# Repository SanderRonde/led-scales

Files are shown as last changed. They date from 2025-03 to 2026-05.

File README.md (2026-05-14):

# LED Scales

A Python-based tool for generating LED scale patterns.

## Preview

Physical build with the web controller driving the LEDs:

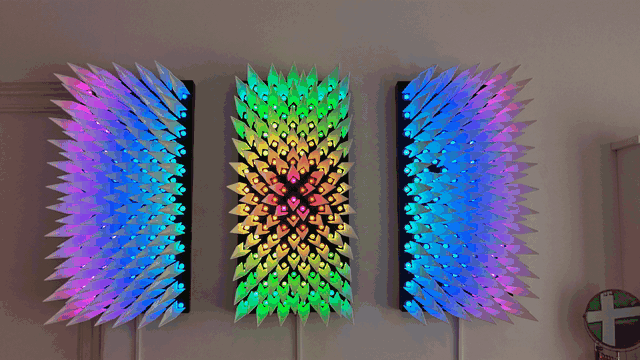
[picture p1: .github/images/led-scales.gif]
LED scales in motion


CAD layout examples (tile patterns generated by this project):

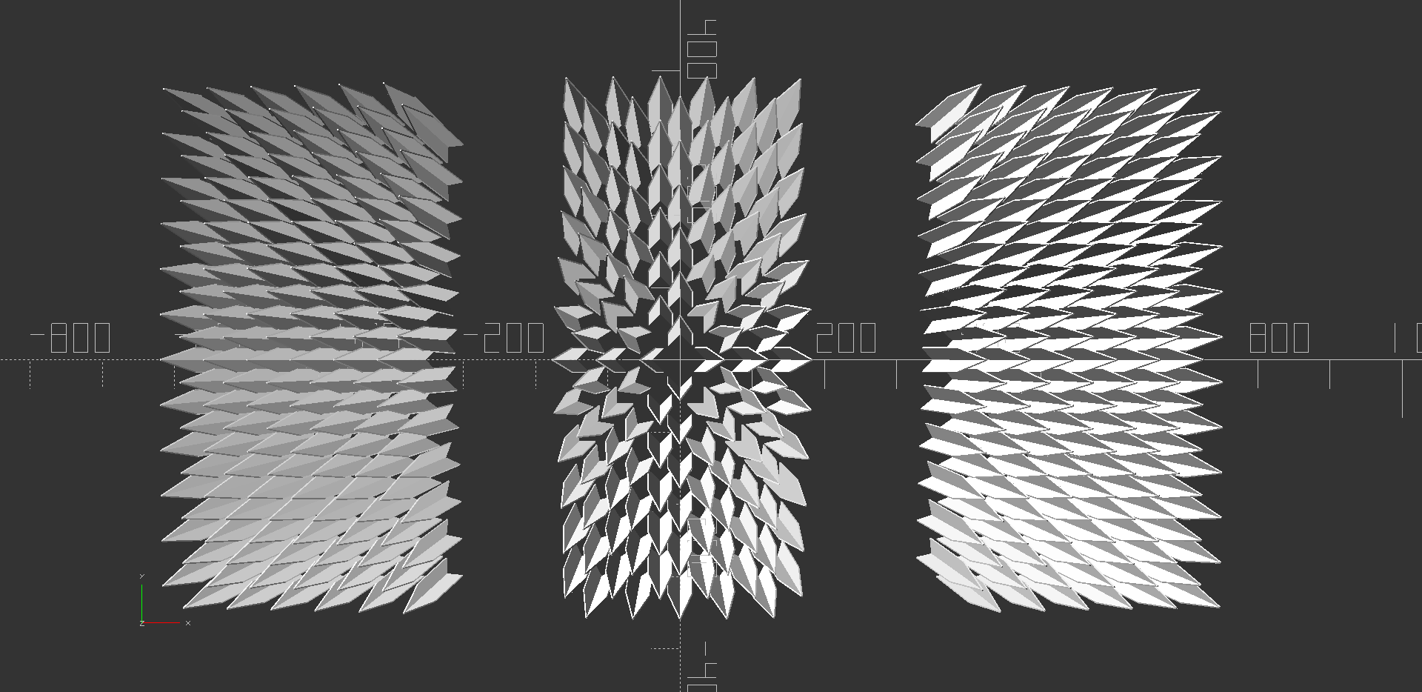
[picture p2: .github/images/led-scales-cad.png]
CAD scale patterns


A higher-quality copy of the clip lives in [`.github/images/led-scales.mp4`](.github/images/led-scales.mp4).

## Project Structure

The project is split into two main components, each with its own virtual environment:
1. CAD Generation (`venv-cad`) - For creating 3D printable scales and panel layouts
2. LED Control (`venv-led`) - For controlling the LED patterns through a web interface

## Virtual Environments

The project uses separate virtual environments for each component to keep dependencies clean and isolated:

- `venv-cad` - Contains dependencies for CAD generation (numpy, openpyscad, scipy)
- `venv-led` - Contains dependencies for LED control (Flask, WebSocket, etc.)

Virtual environments are created and managed automatically when you run the respective commands.

## How to generate files

1. Open `config.py` and set the parameters to your liking. Be sure to update `scad_path` to the path of your OpenSCAD installation.
2. Set up both virtual environments: `python main.py setup`
3. Run `python main.py all` to generate all the necessary files
   - This will automatically use the CAD virtual environment

## Development

- For LED development: `python main.py dev` 
  - Starts a development server with auto-reload
  - Uses the LED virtual environment
- For CAD development: `python main.py generate` (or `2d`/`3d`)
  - Uses the CAD virtual environment
- For linting: `python main.py lint`
  - Uses the CAD virtual environment (contains pylint)

## How to use

1. Inspect the `cad/out` directory to see if the results are satisfactory. Adjust `config.py` if necessary. Also use `python main.py leds-mock` to see what the LEDs will look like.
2. 3D print the tiles in `cad/out/tiles/`. Each tile can be printed on a single build plate. Keep them separated!
3. Order panels (material is up to you, I went with alupanel) with dimensions as outputted by the `all` command above. I'd recommend 3+mm thick.
4. Print out the template in `cad/out/panels/` onto paper.
5. Choose and order LEDs. I went with WS2812B strings (specifically [these](https://aliexpress.com/item/33044727740.html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))
6. Drill holes for the LEDs on the panels (see template for location). Hole size should of course be the same as the LED. Mark the orientation of scales on the panels (I used a knife through the paper).
7. Print diffusers for the LEDs.
8. Wire LEDs through the back of the holes, put a diffuser on the front of the holes, use hot glue to stick them in place.
9. Assemble the scales on the marked locations. By starting out from the middle and simply going through print order you'll increase the curve as you go. Alternatively use `out/led-scales-py.positioning.scad` to get exact locations.
10. Wire LEDs to the power supply.
11. Get a raspberry pi and run the server (`python main.py leds`). Visit the web page to both see a preview and to control the effects.
12. Turn on the power and enjoy!

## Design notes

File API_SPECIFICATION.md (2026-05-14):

# LED Control System - API Specification v1.0

## Overview

This is a comprehensive API specification for the LED Control System. The system provides both HTTP REST endpoints and Socket.IO real-time communication for controlling LED effects, managing power state, brightness, and presets.

**Base URL**: `http://localhost:5001` (configurable via `web_port` in config)

**Transport Protocols**:

-   HTTP/REST for state changes and configuration
-   Socket.IO for real-time LED updates and bidirectional communication

---

## Table of Contents

1. [HTTP REST API](#http-rest-api)
    - [Effects Management](#effects-management)
    - [State Management](#state-management)
    - [Presets Management](#presets-management)
    - [Configuration](#configuration)
    - [Static Assets](#static-assets)
2. [Socket.IO API](#socketio-api)
    - [Events from Server](#events-from-server)
    - [Connection Handling](#connection-handling)
3. [Data Models](#data-models)
4. [Authentication](#authentication)
5. [Error Handling](#error-handling)
6. [Examples](#examples)

---

## HTTP REST API

### Effects Management

#### GET /effects

Get all available effects with their parameters and current effect.

**Request:**

```http
GET /effects HTTP/1.1
Host: localhost:5001
```

**Response:** `200 OK`

```json
{
    "effect_parameters": {
        "RainbowRadialEffect": {
            "speed": {
                "type": "float",
                "description": "Speed of the rainbow animation",
                "value": 0.5
            },
            "intensity": {
                "type": "float",
                "description": "Intensity of the colors",
                "value": 1.0
            }
        },
        "SingleColorEffect": {
            "color": {
                "type": "color",
                "description": "The color to display",
                "value": {
                    "r": 255,
                    "g": 0,
                    "b": 0
                }
            }
        },
        "RandomColorHexEffect": {
            "transition_speed": {
                "type": "float",
                "description": "Speed of color transitions",
                "value": 0.3
            }
        }
    },
    "effect_names": {
        "RainbowRadialEffect": "Rainbow Radial",
        "SingleColorEffect": "Single Color",
        "RandomColorHexEffect": "Random Color Hex",
        "RainbowSpinEffect": "Rainbow Spin",
        "MultiColorRadialEffect": "Multi Color Radial"
    },
    "current_effect": "RainbowRadialEffect"
}
```

**Response Fields:**

-   `effect_parameters` (object): Map of effect class names to their parameter definitions
-   `effect_names` (object): Map of effect class names to human-readable names
-   `current_effect` (string): The currently active effect class name

---

#### POST /effects

Set the current effect and optionally update its parameters.

**Request:**

```http
POST /effects HTTP/1.1
Host: localhost:5001
Content-Type: application/json

{
  "effect_name": "SingleColorEffect",
  "parameters": {
    "color": {
      "r": 255,
      "g": 128,
      "b": 0
    }
  }
}
```

**Request Body:**

-   `effect_name` (string, required): The class name of the effect to activate
-   `parameters` (object, optional): Key-value pairs of parameter names and values

**Response:** `200 OK`

```json
{
    "success": true
}
```

**Error Responses:**

`400 Bad Request` - Missing effect name

```json
{
    "success": false,
    "error": "No effect name provided"
}
```

`404 Not Found` - Effect not found

```json
{
    "success": false,
    "error": "Effect \"InvalidEffect\" not found"
}
```

**Side Effects:**

-   Saves configuration to disk (`~/.led_config.json`)
-   Clears `active_preset_id` since effect/parameters were modified
-   Starts the effect if not already running
-   Emits `effects_update` and `state_update` Socket.IO events to all connected clients

---

### State Management

#### GET /state

Get the current power state, target power state, and brightness.

**Request:**

```http
GET /state HTTP/1.1
Host: localhost:5001
```

**Response:** `200 OK`

```json
{
    "power_state": true,
    "target_power_state": true,
    "brightness": 0.85,
    "active_preset_id": 1697123456789,
    "default_preset_id": 1697123456790,
    "power_on_at_startup": true
}
```

**Response Fields:**

-   `power_state` (boolean): Current power state (may be transitioning)
-   `target_power_state` (boolean): Target power state after fade completes
-   `brightness` (float): Brightness level (0.0 to 1.0)
-   `active_preset_id` (number|null): ID of the currently active preset, or null if no preset is active
-   `default_preset_id` (number|null): ID of the preset applied automatically on server startup, or null if none
-   `power_on_at_startup` (boolean): Whether the server begins with strips powered on after a restart. If the key is absent from disk config, this matches legacy behavior using the last saved `power_state`. Change it with `POST /state` (optional body field).

---

#### POST /state

Update the power state, brightness, and/or startup power preference.

**Request:**

```http
POST /state HTTP/1.1
Host: localhost:5001
Content-Type: application/json

{
  "power_state": false,
  "brightness": 0.5
}
```

**Request (startup preference only):**

```http
POST /state HTTP/1.1
Host: localhost:5001
Content-Type: application/json

{
  "power_on_at_startup": false
}
```

**Request Body:**

-   `power_state` (boolean, optional): Set the target power state
-   `brightness` (float, optional): Set the brightness (0.0 to 1.0)
-   `power_on_at_startup` (boolean, optional): Persist whether strips should start **on** after the next server restart (`false` = start off). Does not change current power unless `power_state` is also sent.

**Response:** `200 OK`

```json
{
    "success": true,
    "power_state": true,
    "target_power_state": false,
    "brightness": 0.5,
    "active_preset_id": null,
    "default_preset_id": 1697123456790,
    "power_on_at_startup": true
}
```

**Notes:**

-   Power state changes trigger a 300ms fade transition
-   During the fade, `power_state` and `target_power_state` will differ
-   Brightness is clamped to range [0.0, 1.0]
-   If `power_on_at_startup` is present but not a JSON boolean, the server returns `400 Bad Request`

**Error Responses:**

`400 Bad Request` — `power_on_at_startup` is not a boolean

```json
{
    "error": "\"power_on_at_startup\" must be a boolean"
}
```

**Side Effects:**

-   Saves configuration to disk
-   Persists `power_on_at_startup` when that field is included in the request body
-   Starts fade transition for power changes
-   Clears `active_preset_id` when brightness is modified
-   Emits `state_update` Socket.IO event to all connected clients

---

### Presets Management

#### GET /presets

Get all saved presets.

**Request:**

```http
GET /presets HTTP/1.1
Host: localhost:5001
```

**Response:** `200 OK`

```json
[
    {
        "id": 1697123456789,
        "name": "Cozy Orange",
        "effect": "SingleColorEffect",
        "brightness": 0.6,
        "parameters": {
            "color": {
                "r": 255,
                "g": 128,
                "b": 0
            }
        }
    },
    {
        "id": 1697123456790,
        "name": "Rainbow Party",
        "effect": "RainbowRadialEffect",
        "brightness": 1.0,
        "parameters": {
            "speed": 0.8
        }
    }
]
```

**Response:** Array of preset objects with:

-   `id` (number): Unique identifier (Unix timestamp in milliseconds)
-   `name` (string): User-defined preset name
-   `effect` (string): Effect class name
-   `brightness` (float): Brightness level (0.0 to 1.0)
-   `parameters` (object): Effect parameters

---

#### POST /presets

Create a new preset or update an existing one.

**Request (Create New):**

```http
POST /presets HTTP/1.1
Host: localhost:5001
Content-Type: application/json

{
  "name": "Cool Blue",
  "effect": "SingleColorEffect",
  "brightness": 0.7,
  "parameters": {
    "color": {
      "r": 0,
      "g": 100,
      "b": 255
    }
  }
}
```

**Request (Update Existing):**

```http
POST /presets HTTP/1.1
Host: localhost:5001
Content-Type: application/json

{
  "id": 1697123456789,
  "name": "Updated Name",
  "effect": "SingleColorEffect",
  "brightness": 0.8,
  "parameters": {
    "color": {
      "r": 200,
      "g": 100,
      "b": 50
    }
  }
}
```

**Request Body:**

-   `id` (number, optional): If provided, updates existing preset with this ID
-   `name` (string, required): Preset name
-   `effect` (string, required): Effect class name
-   `brightness` (float, required): Brightness level (0.0 to 1.0)
-   `parameters` (object, required): Effect parameters

**Response:** `200 OK`

```json
{
    "id": 1697123456791,
    "name": "Cool Blue",
    "effect": "SingleColorEffect",
    "brightness": 0.7,
    "parameters": {
        "color": {
            "r": 0,
            "g": 100,
            "b": 255
        }
    }
}
```

**Error Response:** `400 Bad Request`

```json
{
    "error": "Invalid preset data"
}
```

**Side Effects:**

-   Saves configuration to disk
-   Emits `presets_update` Socket.IO event to all connected clients

---

#### DELETE /presets/{preset_id}

Delete a preset by ID.

**Request:**

```http
DELETE /presets/1697123456789 HTTP/1.1
Host: localhost:5001
```

**Response:** `200 OK`

```json
{
    "success": true
}
```

**Side Effects:**

-   Saves configuration to disk
-   Emits `presets_update` Socket.IO event to all connected clients
-   If the deleted preset was the startup default, clears `default_preset_id` and emits `state_update`

---

#### POST /presets/default

Set or clear which preset is applied automatically when the LED server starts. This does not change the current effect until the next restart (unless you also call `POST /presets/apply`).

**Request:**

```http
POST /presets/default HTTP/1.1
Host: localhost:5001
Content-Type: application/json

{
  "id": 1697123456789
}
```

**Request Body:**

-   `id` (number|null, required): Preset ID to use on startup, or `null` to clear the default

**Response:** `200 OK`

```json
{
    "success": true,
    "default_preset_id": 1697123456789
}
```

When clearing the default:

```json
{
    "success": true,
    "default_preset_id": null
}
```

**Error Responses:**

`400 Bad Request` — Missing `id` key

```json
{
    "error": "JSON body must include \"id\" (preset id or null to clear)"
}
```

`404 Not Found` — Preset id is not in the saved presets list

```json
{
    "error": "Preset not found"
}
```

**Side Effects:**

-   Saves `default_preset_id` to `~/.led_config.json`
-   Emits `state_update` Socket.IO event to all connected clients

---

#### POST /presets/apply

Apply a preset to the LED system.

**Request:**

```http
POST /presets/apply HTTP/1.1
Host: localhost:5001
Content-Type: application/json

{
  "id": 1697123456789,
  "effect": "SingleColorEffect",
  "brightness": 0.7,
  "parameters": {
    "color": {
      "r": 0,
      "g": 100,
      "b": 255
    }
  }
}
```

**Request Body:**

-   `id` (number, optional): Preset ID to set as active
-   `effect` (string, required): Effect class name
-   `brightness` (float, optional): Brightness level (0.0 to 1.0)
-   `parameters` (object, optional): Effect parameters

**Response:** `200 OK`

```json
{
    "success": true
}
```

**Error Response:** `400 Bad Request`

```json
{
    "error": "No preset data provided"
}
```

**Side Effects:**

-   Changes current effect
-   Updates effect parameters
-   Sets brightness
-   Sets `active_preset_id` to the preset's ID
-   Saves configuration to disk
-   Starts effect if not running
-   Emits `effects_update` and `state_update` Socket.IO events

---

### Configuration

#### GET /config

Get the visualizer configuration (LED layout and controller type).

**Request:**

```http
GET /config HTTP/1.1
Host: localhost:5001
```

**Response (Hexagon Layout):** `200 OK`

```json
{
  "type": "hex",
  "led_count": 488,
  "hexagons": [
    {
      "x": 0,
      "y": 1,
      "ordered_leds": [216, 217, 218, 219, 220, 248, 249, 250, 251, 252, ...]
    },
    {
      "x": 0,
      "y": 2,
      "ordered_leds": [189, 190, 191, 192, 193, 303, 304, 305, 306, ...]
    }
  ]
}
```

**Response (Scale Panel Layout):** `200 OK`

```json
{
    "type": "scale",
    "led_count": 648,
    "panels": [
        {
            "panel_index": 0,
            "x_offset": 0,
            "y_offset": 0,
            "led_positions": [
                { "index": 0, "x": 27.5, "y": 27.5 },
                { "index": 1, "x": 82.5, "y": 27.5 }
            ]
        }
    ],
    "spacing": 55,
    "panel_width": 330,
    "panel_height": 632.5
}
```

**Response Fields:**

Common:

-   `type` (string): Layout type - `"hex"` or `"scale"`
-   `led_count` (number): Total number of LEDs

Hex Layout:

-   `hexagons` (array): Array of hexagon objects
    -   `x` (number): Hexagon X position
    -   `y` (number): Hexagon Y position (may be half-integer for offset rows)
    -   `ordered_leds` (array): LED indices in this hexagon, in spiral order

Scale Layout:

-   `panels` (array): Array of panel objects
    -   `panel_index` (number): Panel index
    -   `x_offset` (number): Panel X offset in mm
    -   `y_offset` (number): Panel Y offset in mm
    -   `led_positions` (array): LED positions within panel
        -   `index` (number): Global LED index
        -   `x` (number): X position in mm
        -   `y` (number): Y position in mm
-   `spacing` (number): Spacing between LEDs in mm
-   `panel_width` (number): Panel width in mm
-   `panel_height` (number): Panel height in mm

---

### Static Assets

#### GET /

Serves the main visualizer web interface.

**Request:**

```http
GET / HTTP/1.1
Host: localhost:5001
```

**Response:** `200 OK`

```html
<!DOCTYPE html>
<html>
    <head>
        <title>LED Visualizer</title>
        ...
    </head>
    <body>
        ...
    </body>
</html>
```

---

#### GET /static/{filename}

Serves static files (JavaScript, CSS, images).

**Request:**

```http
GET /static/js/index.js HTTP/1.1
Host: localhost:5001
```

**Response:** `200 OK`

```javascript
// JavaScript content
```

**Supported File Types:**

-   `.js` - JavaScript files (MIME: `application/javascript`)
-   `.css` - CSS files (MIME: `text/css`)
-   `.html` - HTML files (MIME: `text/html`)
-   `.json` - JSON files (MIME: `application/json`)
-   `.svg` - SVG images (MIME: `image/svg+xml`)

---

## Socket.IO API

### Connection

**Endpoint:** `ws://localhost:5001/socket.io/`

**Namespace:** `/` (default namespace)

**CORS:** Allowed from all origins (`*`)

**Protocol:** Socket.IO v4 compatible

### Connection Handling

#### Event: `connect`

Emitted by client when connecting to the server.

**Server Response:**

Upon connection, the server automatically emits three events:

1. `state_update` - Current power and brightness state
2. `effects_update` - Available effects and current effect
3. `presets_update` - All saved presets

**Example Client Code:**

```javascript
import io from "socket.io-client";

const socket = io("http://localhost:5001");

socket.on("connect", () => {
    console.log("Connected to LED server");
});
```

---

### Events from Server

#### Event: `led_update`

Real-time LED color data. Emitted continuously (approx 20-200 times per second depending on configuration).

**Payload:**

```json
{
  "leds": [
    {"r": 255, "g": 0, "b": 0, "w": 0},
    {"r": 255, "g": 32, "b": 0, "w": 0},
    {"r": 255, "g": 64, "b": 0, "w": 0},
    ...
  ]
}
```

**Payload Fields:**

-   `leds` (array): Array of LED color objects in index order
    -   `r` (number): Red component (0-255)
    -   `g` (number): Green component (0-255)
    -   `b` (number): Blue component (0-255)
    -   `w` (number): White component (0-255)

**Client Handler Example:**

```javascript
socket.on("led_update", (data) => {
    // Update visualizer with new LED colors
    data.leds.forEach((color, index) => {
        updateLED(index, color);
    });
});
```

---

#### Event: `state_update`

Emitted when power state, brightness, startup default preset, or startup power preference changes.

**Payload:**

```json
{
    "power_state": true,
    "target_power_state": false,
    "brightness": 0.75,
    "active_preset_id": 1697123456789,
    "default_preset_id": 1697123456790,
    "power_on_at_startup": true
}
```

**Payload Fields:**

-   `power_state` (boolean): Current power state
-   `target_power_state` (boolean): Target power state (differs during fade)
-   `brightness` (float): Brightness level (0.0 to 1.0)
-   `active_preset_id` (number|null): ID of the currently active preset, or null if no preset is active
-   `default_preset_id` (number|null): ID of the preset applied on server startup, or null if none
-   `power_on_at_startup` (boolean): Whether the server will start with power on after the next restart

**Triggered By:**

-   Client connects
-   `POST /state` (power, brightness, and/or `power_on_at_startup`)
-   Preset applied
-   `POST /presets/default`
-   `DELETE /presets/{id}` when the removed preset was the startup default

**Client Handler Example:**

```javascript
socket.on("state_update", (data) => {
    console.log(
        `Power: ${data.power_state}, Brightness: ${data.brightness * 100}%`
    );
    console.log(`Active preset: ${data.active_preset_id || "None"}`);
    console.log(`Startup default: ${data.default_preset_id || "None"}`);
    console.log(`Power on at next startup: ${data.power_on_at_startup}`);
    updatePowerButton(data.power_state);
    updateBrightnessSlider(data.brightness);
    highlightActivePreset(data.active_preset_id);
});
```

---

#### Event: `effects_update`

Emitted when the current effect or available effects change.

**Payload:**

```json
{
    "effect_parameters": {
        "RainbowRadialEffect": {
            "speed": {
                "type": "float",
                "description": "Animation speed",
                "value": 0.5
            }
        },
        "SingleColorEffect": {
            "color": {
                "type": "color",
                "description": "Display color",
                "value": { "r": 255, "g": 0, "b": 0 }
            }
        }
    },
    "effect_names": {
        "RainbowRadialEffect": "Rainbow Radial",
        "SingleColorEffect": "Single Color"
    },
    "current_effect": "RainbowRadialEffect"
}
```

**Payload Fields:**

-   `effect_parameters` (object): Map of effect class names to parameter definitions
-   `effect_names` (object): Map of effect class names to display names
-   `current_effect` (string): Currently active effect class name

**Triggered By:**

-   Client connects
-   POST /effects endpoint called
-   Effect changed via preset

**Client Handler Example:**

```javascript
socket.on("effects_update", (data) => {
    console.log(`Current effect: ${data.effect_names[data.current_effect]}`);
    populateEffectDropdown(data.effect_names);
    populateParameterControls(data.effect_parameters[data.current_effect]);
});
```

---

#### Event: `presets_update`

Emitted when presets are added, modified, or deleted.

**Payload:**

```json
[
    {
        "id": 1697123456789,
        "name": "Cozy Orange",
        "effect": "SingleColorEffect",
        "brightness": 0.6,
        "parameters": {
            "color": { "r": 255, "g": 128, "b": 0 }
        }
    },
    {
        "id": 1697123456790,
        "name": "Party Mode",
        "effect": "RainbowSpinEffect",
        "brightness": 1.0,
        "parameters": {
            "speed": 0.9
        }
    }
]
```

**Payload:** Array of preset objects (see [GET /presets](#get-presets) for structure)

**Triggered By:**

-   Client connects
-   POST /presets endpoint called (create/update)
-   DELETE /presets/{id} endpoint called

**Client Handler Example:**

```javascript
socket.on("presets_update", (presets) => {
    console.log(`${presets.length} presets available`);
    renderPresetList(presets);
});
```

---

## Data Models

### Parameter Types

Parameters define configurable aspects of effects. There are four types:

#### Float Parameter

```json
{
    "type": "float",
    "description": "A floating point value",
    "value": 0.75
}
```

-   **Range:** 0.0 to 1.0 (normalized)
-   **Used for:** Speed, intensity, opacity, etc.

#### Color Parameter

```json
{
    "type": "color",
    "description": "An RGB color",
    "value": {
        "r": 255,
        "g": 128,
        "b": 64
    }
}
```

-   **Components:** r, g, b (0-255 each)
-   **Note:** White component (w) is not user-configurable

#### Enum Parameter

```json
{
    "type": "enum",
    "description": "A choice from predefined values",
    "value": "fast",
    "enum_values": ["slow", "medium", "fast"]
}
```

-   **Used for:** Mode selection, pattern types, etc.

#### Color List Parameter

```json
{
    "type": "color_list",
    "description": "A list of colors",
    "value": [
        { "r": 255, "g": 0, "b": 0 },
        { "r": 0, "g": 255, "b": 0 },
        { "r": 0, "g": 0, "b": 255 }
    ]
}
```

-   **Used for:** Multi-color effects, gradients, palettes

---

### RGBW Color Model

All LED colors use RGBW format:

```json
{
    "r": 255,
    "g": 128,
    "b": 0,
    "w": 0
}
```

-   `r` (number): Red component (0-255)
-   `g` (number): Green component (0-255)
-   `b` (number): Blue component (0-255)
-   `w` (number): White component (0-255)

**Note:** The white component is typically controlled internally by the system and not exposed in user-facing color parameters.

---

### Effect Definition

An effect is a Python class that generates LED animations. Each effect has:

-   **Class name**: e.g., `RainbowRadialEffect`
-   **Display name**: e.g., `"Rainbow Radial"`
-   **Parameters**: Configurable values (see Parameter Types)

Common effects include:

-   `RainbowRadialEffect` - Rainbow emanating from center
-   `RainbowSpinEffect` - Rotating rainbow pattern
-   `SingleColorEffect` - Static single color
-   `SingleColorRadialEffect` - Single color pulsing from center
-   `MultiColorRadialEffect` - Multiple colors pulsing from center
-   `RandomColorSingleEffect` - Random colors for all LEDs
-   `RandomColorDualEffect` - Random colors in pairs
-   `RandomColorHexEffect` - Random colors per hexagon (hex layout only)

---

## Authentication

**Current Status:** No authentication is implemented.

**Security Note:** The API is designed for local network use. If exposing to the internet, implement:

-   Authentication (API keys or OAuth)
-   HTTPS/WSS encryption
-   Rate limiting
-   Input validation

---

## Error Handling

### HTTP Error Responses

All error responses follow this format:

```json
{
    "error": "Human-readable error message",
    "success": false
}
```

**Common Status Codes:**

-   `400 Bad Request` - Invalid request data
-   `404 Not Found` - Resource not found (effect, preset, etc.)
-   `500 Internal Server Error` - Server-side error

### Socket.IO Error Handling

Socket.IO connections may fail or disconnect. Handle these events:

```javascript
socket.on("connect_error", (error) => {
    console.error("Connection failed:", error);
});

socket.on("disconnect", (reason) => {
    console.log("Disconnected:", reason);
    // Attempt reconnection
});
```

Socket.IO client will automatically attempt to reconnect on disconnection.

---

## Examples

### Example 1: Basic Client Connection

```javascript
import io from "socket.io-client";

// Connect to the server
const socket = io("http://localhost:5001");

// Listen for LED updates
socket.on("led_update", (data) => {
    console.log(`Received colors for ${data.leds.length} LEDs`);
});

// Listen for state changes
socket.on("state_update", (state) => {
    console.log(`Power: ${state.power_state}, Brightness: ${state.brightness}`);
});

// Listen for effect changes
socket.on("effects_update", (effects) => {
    console.log(`Current effect: ${effects.current_effect}`);
});
```

---

### Example 2: Change Effect with Parameters

```javascript
// Set effect to single color orange
async function setOrangeColor() {
    const response = await fetch("http://localhost:5001/effects", {
        method: "POST",
        headers: {
            "Content-Type": "application/json",
        },
        body: JSON.stringify({
            effect_name: "SingleColorEffect",
            parameters: {
                color: {
                    r: 255,
                    g: 128,
                    b: 0,
                },
            },
        }),
    });

    const result = await response.json();
    console.log("Effect applied:", result.success);
}
```

---

### Example 3: Power Control with Fade

```javascript
// Turn off LEDs (with 300ms fade)
async function powerOff() {
    const response = await fetch("http://localhost:5001/state", {
        method: "POST",
        headers: {
            "Content-Type": "application/json",
        },
        body: JSON.stringify({
            power_state: false,
        }),
    });

    const state = await response.json();
    console.log("Target power state:", state.target_power_state);

    // The actual power_state will transition over 300ms
    setTimeout(() => {
        console.log("Fade complete");
    }, 300);
}
```

---

### Example 4: Brightness Control

```javascript
// Set brightness to 50%
async function setBrightness(percent) {
    const response = await fetch("http://localhost:5001/state", {
        method: "POST",
        headers: {
            "Content-Type": "application/json",
        },
        body: JSON.stringify({
            brightness: percent / 100,
        }),
    });

    const state = await response.json();
    console.log("New brightness:", state.brightness);
}

setBrightness(50);
```

---

### Example 5: Save and Apply Preset

```javascript
// Save current state as a preset
async function savePreset(name) {
    // First, get current state
    const stateResponse = await fetch("http://localhost:5001/state");
    const state = await stateResponse.json();

    const effectsResponse = await fetch("http://localhost:5001/effects");
    const effects = await effectsResponse.json();

    // Get current effect parameters
    const currentEffectParams =
        effects.effect_parameters[effects.current_effect];

    // Extract parameter values
    const parameters = {};
    for (const [paramName, param] of Object.entries(currentEffectParams)) {
        parameters[paramName] = param.value;
    }

    // Save preset
    const saveResponse = await fetch("http://localhost:5001/presets", {
        method: "POST",
        headers: {
            "Content-Type": "application/json",
        },
        body: JSON.stringify({
            name: name,
            effect: effects.current_effect,
            brightness: state.brightness,
            parameters: parameters,
        }),
    });

    const savedPreset = await saveResponse.json();
    console.log("Preset saved:", savedPreset);
    return savedPreset;
}

// Apply a preset
async function applyPreset(preset) {
    const response = await fetch("http://localhost:5001/presets/apply", {
        method: "POST",
        headers: {
            "Content-Type": "application/json",
        },
        body: JSON.stringify({
            id: preset.id,
            effect: preset.effect,
            brightness: preset.brightness,
            parameters: preset.parameters,
        }),
    });

    const result = await response.json();
    console.log("Preset applied:", result.success);

    // The active_preset_id will now be set to preset.id
    // You'll receive a state_update event with the new active_preset_id
}

// Usage
const myPreset = await savePreset("My Favorite");
// Later...
await applyPreset(myPreset);
```

---

### Example 6: Active Preset Tracking

```javascript
// This example demonstrates how active_preset_id is tracked and cleared

// 1. Apply a preset
async function demonstrateActivePreset() {
    // Get a preset
    const presetsResponse = await fetch("http://localhost:5001/presets");
    const presets = await presetsResponse.json();
    const myPreset = presets[0]; // Use first preset

    // Apply the preset
    await fetch("http://localhost:5001/presets/apply", {
        method: "POST",
        headers: { "Content-Type": "application/json" },
        body: JSON.stringify({
            id: myPreset.id,
            effect: myPreset.effect,
            brightness: myPreset.brightness,
            parameters: myPreset.parameters,
        }),
    });

    // Check state - active_preset_id should be set
    let stateResponse = await fetch("http://localhost:5001/state");
    let state = await stateResponse.json();
    console.log(`Active preset after applying: ${state.active_preset_id}`);
    // Output: Active preset after applying: 1697123456789

    // 2. Change brightness - this will clear active_preset_id
    await fetch("http://localhost:5001/state", {
        method: "POST",
        headers: { "Content-Type": "application/json" },
        body: JSON.stringify({ brightness: 0.8 }),
    });

    // Check state again - active_preset_id should be null
    stateResponse = await fetch("http://localhost:5001/state");
    state = await stateResponse.json();
    console.log(
        `Active preset after brightness change: ${state.active_preset_id}`
    );
    // Output: Active preset after brightness change: null

    // 3. Apply preset again
    await fetch("http://localhost:5001/presets/apply", {
        method: "POST",
        headers: { "Content-Type": "application/json" },
        body: JSON.stringify({
            id: myPreset.id,
            effect: myPreset.effect,
            brightness: myPreset.brightness,
            parameters: myPreset.parameters,
        }),
    });

    // 4. Change effect - this will also clear active_preset_id
    await fetch("http://localhost:5001/effects", {
        method: "POST",
        headers: { "Content-Type": "application/json" },
        body: JSON.stringify({
            effect_name: "RainbowRadialEffect",
            parameters: { speed: 0.5 },
        }),
    });

    // Check state - active_preset_id should be null again
    stateResponse = await fetch("http://localhost:5001/state");
    state = await stateResponse.json();
    console.log(`Active preset after effect change: ${state.active_preset_id}`);
    // Output: Active preset after effect change: null
}

// Listen for state updates via WebSocket
socket.on("state_update", (data) => {
    if (data.active_preset_id) {
        console.log(`Preset ${data.active_preset_id} is active`);
        // Highlight the active preset in UI
    } else {
        console.log("No preset is active (manual settings)");
        // Clear any preset highlighting in UI
    }
});
```

---

### Example 7: List All Effects

```javascript
async function listEffects() {
    const response = await fetch("http://localhost:5001/effects");
    const data = await response.json();

    console.log("Available Effects:");
    for (const [className, displayName] of Object.entries(data.effect_names)) {
        console.log(`- ${displayName} (${className})`);

        const params = data.effect_parameters[className];
        if (params) {
            console.log("  Parameters:");
            for (const [paramName, param] of Object.entries(params)) {
                console.log(
                    `    - ${paramName}: ${param.type} = ${JSON.stringify(
                        param.value
                    )}`
                );
            }
        }
    }
}
```

---

### Example 8: Python Client Example

```python
import requests
import socketio

# HTTP REST client
class LEDClient:
    def __init__(self, base_url='http://localhost:5001'):
        self.base_url = base_url

    def get_state(self):
        response = requests.get(f'{self.base_url}/state')
        return response.json()

    def set_power(self, power_on):
        response = requests.post(
            f'{self.base_url}/state',
            json={'power_state': power_on}
        )
        return response.json()

    def set_brightness(self, brightness):
        response = requests.post(
            f'{self.base_url}/state',
            json={'brightness': brightness}
        )
        return response.json()

    def set_effect(self, effect_name, parameters=None):
        data = {'effect_name': effect_name}
        if parameters:
            data['parameters'] = parameters
        response = requests.post(
            f'{self.base_url}/effects',
            json=data
        )
        return response.json()

    def get_presets(self):
        response = requests.get(f'{self.base_url}/presets')
        return response.json()

# Socket.IO client
sio = socketio.Client()

@sio.on('connect')
def on_connect():
    print('Connected to LED server')

@sio.on('led_update')
def on_led_update(data):
    print(f'Received {len(data["leds"])} LED colors')

@sio.on('state_update')
def on_state_update(data):
    print(f'Power: {data["power_state"]}, Brightness: {data["brightness"]}')

# Usage
if __name__ == '__main__':
    # REST API
    client = LEDClient()
    print(client.get_state())
    client.set_effect('SingleColorEffect', {
        'color': {'r': 255, 'g': 0, 'b': 0}
    })

    # Socket.IO
    sio.connect('http://localhost:5001')
    sio.wait()
```

---

### Example 9: Retrieve LED Layout Configuration

```javascript
async function getLayoutInfo() {
    const response = await fetch("http://localhost:5001/config");
    const config = await response.json();

    console.log(`Layout type: ${config.type}`);
    console.log(`Total LEDs: ${config.led_count}`);

    if (config.type === "hex") {
        console.log(`Hexagons: ${config.hexagons.length}`);
        config.hexagons.forEach((hex, index) => {
            console.log(
                `  Hex ${index}: position (${hex.x}, ${hex.y}), ${hex.ordered_leds.length} LEDs`
            );
        });
    } else if (config.type === "scale") {
        console.log(`Panels: ${config.panels.length}`);
        console.log(
            `Panel size: ${config.panel_width}mm x ${config.panel_height}mm`
        );
    }
}
```

---

## Implementation Notes

### Configuration Persistence

All configuration is stored in a single JSON file at `~/.led_config.json`. This includes:

-   Current effect and parameters
-   Power state
-   Brightness level
-   Active preset ID
-   Default preset ID (applied on server startup)
-   `power_on_at_startup` (whether strips start on after a server restart)
-   All saved presets

The file is automatically saved whenever:

-   Effect is changed
-   Parameters are updated
-   Power state is changed
-   Brightness is changed
-   Presets are created, updated, or deleted
-   Active preset is changed
-   Startup default preset is set or cleared
-   Startup power preference is changed via `POST /state` (`power_on_at_startup` field)

### Active Preset Tracking

The system tracks which preset is currently active via the `active_preset_id` field:

-   **Set on preset application**: When a preset is applied via `POST /presets/apply`, the `active_preset_id` is set to the preset's ID
-   **Cleared on manual changes**: The `active_preset_id` is set to `null` when:
    -   A different effect is selected via `POST /effects`
    -   Effect parameters are modified via `POST /effects`
    -   Brightness is changed via `POST /state`
-   **Persisted**: The active preset ID is saved to `~/.led_config.json` and restored on restart
-   **Included in state**: The `active_preset_id` is included in all state responses and `state_update` Socket.IO events

This allows UI clients to highlight which preset is currently active and automatically clear the highlight when the user makes manual adjustments.

### Startup default preset

The `default_preset_id` field (also in `~/.led_config.json`) chooses a saved preset to **apply when the server process starts**, after the last-saved effect is loaded. If the id is missing from presets, refers to an unknown effect, or the field is null, the server keeps the normal saved-effect behavior. Setting the default via `POST /presets/default` does not apply the preset immediately; use `POST /presets/apply` for that.

### Power on at startup

The `power_on_at_startup` boolean (in `~/.led_config.json`) sets **initial power** when the server starts. It is independent of the live `power_state` saved during operation (so you can turn lights off before shutdown without changing the next-boot preference until you change this setting). If `power_on_at_startup` has never been written, the server uses the legacy rule: initial power matches the last saved `power_state`.

### Fade Transition

Power state changes include a 300ms fade transition:

-   **Fade duration**: 300ms (configurable via `_fade_duration` in code)
-   **During fade**: `power_state` differs from `target_power_state`
-   **After fade**: `power_state` equals `target_power_state`

The fade is implemented by gradually adjusting brightness from 0 to current brightness (fade in) or current brightness to 0 (fade out).

### Effect Loop Timing

Effects run in a continuous loop with sleep times:

-   **Mock mode**: 50ms sleep (20 FPS)
-   **Real hardware**: 5ms sleep (up to 200 FPS)

The actual FPS depends on effect complexity and hardware performance.

### Debug Mode

When started with `--debug` flag, the server prints FPS statistics every second:

```
FPS: 47.23
FPS: 48.01
FPS: 47.89
```

This is useful for performance tuning but should not be used in production.

---

## Version History

-   **v1.1** (2025) - Active Preset Tracking
    -   Added `active_preset_id` field to state responses
    -   Tracks which preset is currently active
    -   Automatically clears when manual changes are made
    -   Persists active preset across restarts
-   **v1.0** (2024) - Initial API specification
    -   HTTP REST endpoints for effects, state, presets, configuration
    -   Socket.IO real-time LED updates
    -   Support for hexagon and scale panel layouts
    -   Preset management
    -   Power control with fade transitions
    -   Brightness control

---

## Support & Contact

For issues or questions about this API:

1. Check the README.md file
2. Review the source code in `leds/leds.py`
3. Examine client examples in `leds/static/js/`

---

## License

This API specification and implementation are part of the LED Control System project.

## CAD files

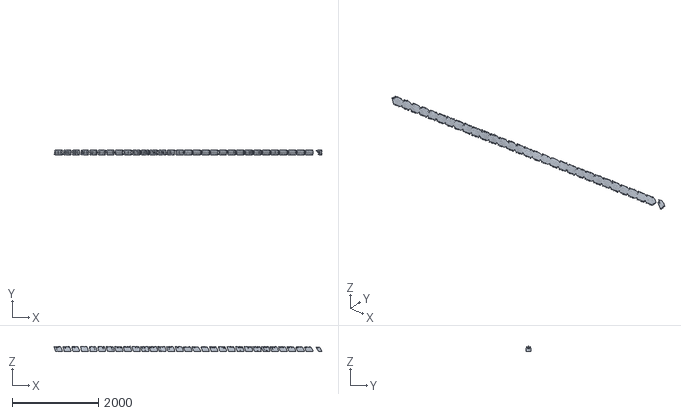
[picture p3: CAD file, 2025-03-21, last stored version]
led-scales-printable.stl
6199.1 x 116.1 x 120.2

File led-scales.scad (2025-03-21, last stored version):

baseLength = 25; // [30:1:50]
baseWidth = 2; // [2:1:10]
tipWidth = 5; // [2:1:10]
baseHeight = 110; // [100:1:250]
spikeSize = 50; // [50:1:100]

spacing = 55; // [50:1:100]
xCount = 6; // [6:2:20]
yCount = 12; // [6:2:20]

leanBase = 5; // [0:1:10]
leanFactor = 0.05; // [0.01:0.01:0.1]

panelCount = 3; // [1:2:9]
panelSpacing = 80; // [0:1:100]

ledDiameter = 10; // [1:1:20]
is2D = false; // [true, false]
isFast = false; // [true, false]

estimatedWeightG = 23/2; // [10:1:500]
pricePerKilo = 20; // [10:1:100]

// TODO:(sander) consider:
// Log every possible `distance`
// Calculate anew using every `distance` but sort of order this array
// Then do tiling

isPrint = true; // [true, false]
printBedSpacing = 400; // [100:1:500]
xPerBuildPlate = 5;
yPerBuildPlate = 5;

spikeHeight = baseHeight - spikeSize;

finalSpacing = isPrint ? ((sqrt(baseLength * baseLength + baseLength * baseLength)) + 5) : spacing;
finalPanelSpacing = isPrint ? 0 : panelSpacing;

module scaleHalf(isRotated) {
    translate([0, 0, -spikeHeight]) {
        cube([baseLength, baseWidth, spikeHeight]);
    };
    cube([baseLength, baseWidth, spikeHeight]);
    translate([0, baseWidth, spikeHeight])
        rotate([90, 0, 0])
            linear_extrude(height=baseWidth)
                polygon(points=[[0,0], [baseLength,0], [tipWidth, spikeHeight]], paths=[[0,1,2]]);
    translate([0, 0, spikeHeight])
    cube([tipWidth, tipWidth, spikeHeight]);
}

module scale3D(distance) {
    distanceFromCenter = sqrt(baseLength);
    sizeOfScale = baseLength + baseWidth;
    leanAngle = leanBase + (distance * leanFactor);
    translate([-sqrt(sizeOfScale * sizeOfScale / 2), 0, 0]) {
        rotate([0, -leanAngle, 0]) {
            rotate([0, 0, -45]) {
                scaleHalf();
            }
            translate([sqrt(baseWidth), sqrt(baseWidth), 0])
            translate([0, -(baseWidth * sqrt(2)), 0])
            rotate([-0, 0, 45]) {
                scaleHalf();
            }
        }
    }
}



module scale(distance) {
    if (is2D) {
        translate([0, 0, 0]) {
            circle(d=ledDiameter);
        }
        projection(cut=true) {
            scale3D(distance);
        };
    } else {
        scale3D(distance);
    }
}

module drawPanel(scaleXOffset, scaleYOffset) {
    for (_i = [-xCount / 2:1:xCount / 2]) {
        i = _i + scaleXOffset;
        for (_j = [-yCount / 2:1:yCount / 2]) {
            j = _j + scaleYOffset;
            distance = sqrt(i*i + j*j) * finalSpacing;
            translate([-(i * finalSpacing) - (finalSpacing / 2), -(j * finalSpacing), 0]) {
                rotate([0, 0, isPrint ? 0 : atan2(j, i + 0.5)])
                scale(distance);
            }
            translate([-(i * finalSpacing), -(j * finalSpacing) - (finalSpacing / 2), 0]) {
                rotate([0, 0, isPrint ? 0 : atan2(j + 0.5, i)])
                scale(distance);
            };
        }
    }
}

totalWidth = (xCount + 1) * finalSpacing * panelCount + (finalPanelSpacing * (panelCount - 1));
totalHeight = (yCount + 1) * finalSpacing;
if (isPrint) {
    totalPerBuildPlate = xPerBuildPlate * yPerBuildPlate;
    echo("xPerBuildPlate is ", xPerBuildPlate);
    echo("yPerBuildPlate is ", yPerBuildPlate);
    echo("totalPerBuildPlate is ", totalPerBuildPlate);

    difference() {
        union() {
            for (p = [0:1:((panelCount - 1) / 2)]) {
                for (invert = [-1, 1]) {
                    for (_i = [-xCount / 2:1:xCount / 2]) {
                        i = _i + (invert  * p * xCount);
                        for (j = [-yCount / 2:1:yCount / 2]) {
                            distance = sqrt(i*i + j*j) * finalSpacing;

                            totalCount = (p * 2 * (xCount + 1) * (yCount + 1)) + 
                                ((invert + 1) / 2 * (xCount + 1) * (yCount + 1)) + 
                                ((_i + xCount / 2) * (yCount + 1)) + 
                                (j + yCount / 2);

                            buildPlateIndex = floor(totalCount / totalPerBuildPlate);
                            remainder = totalCount % totalPerBuildPlate;
                            buildPlateX = floor(remainder / xPerBuildPlate);
                            buildPlateY = remainder % xPerBuildPlate;

                            translate([(buildPlateIndex * printBedSpacing) -(buildPlateX * finalSpacing) - (finalSpacing / 2), -(buildPlateY * finalSpacing), 0]) {
                                rotate([0, 0, isPrint ? 0 : atan2(j, i + 0.5)])
                                scale(distance);
                            }
                            translate([(buildPlateIndex * printBedSpacing) -(buildPlateX * finalSpacing), -(buildPlateY * finalSpacing), 0]) {
                                rotate([0, 0, isPrint ? 0 : atan2(j, i + 0.5)])
                                scale(distance);
                            };
                        }
                    }
                }
            }
        }
        translate([(-totalWidth / 2) * 1.5, (-totalHeight / 2) * 1.5, -baseHeight * 1.5]) {
            cube([totalWidth * 50, totalHeight * 1.5, baseHeight * 1.5]);
        }
    }
} else {
    difference() {
        union() {
            drawPanel(0, 0, xCount, yCount);
            for (i = [1:1:((panelCount - 1) / 2)]) {
                translate([-i * finalPanelSpacing, 0, 0]) {
                    drawPanel(((i) * xCount) + 1, 0, xCount, yCount);
                };
                translate([i * finalPanelSpacing, 0, 0]) {
                    drawPanel(-(i * xCount) - 1, 0, xCount, yCount);
                };
            }
        }
        if (!isFast) {
            translate([(-totalWidth / 2) * 1.5, (-totalHeight / 2) * 1.5, -baseHeight * 1.5]) {
                cube([totalWidth * 1.5, totalHeight * 1.5, baseHeight * 1.5]);
            }
        }
    }
}

echo("Panel dimensions are ", totalWidth, "x", totalHeight);
echo("Panel count is ", panelCount);
echo("Total width is ", totalWidth);
echo("Scale count is ", xCount * yCount * panelCount);
echo("Estimated weight is ", estimatedWeightG * xCount * yCount * panelCount / 1000, "kg");
echo("Estimated price is €", estimatedWeightG * xCount * yCount * panelCount / 1000 * pricePerKilo);

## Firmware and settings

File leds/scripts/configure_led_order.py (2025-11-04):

#!/usr/bin/env python3
"""
LED Order Configuration Script

This script helps configure the LED ordering for hexagonal layouts where:
- Each hexagon has multiple LEDs
- The first LED should be at the bottom
- LEDs should be ordered counter-clockwise from the bottom

Usage:
1. Run the script - it will show each hexagon's LEDs in different colors
2. Identify which LED is at the bottom position
3. The script will shift the array to make that LED first
4. Test the final configuration with rainbow patterns
"""

import sys
from typing import List, Tuple
from pathlib import Path

# Add parent directories to path
sys.path.append(str(Path(__file__).parent.parent.parent))

from config import HexConfig, get_config, ConfigMode
from leds.color import RGBW
from leds.controllers.controller_base import get_library


class LEDOrderConfigurator:
    def __init__(self):
        self.config = get_config(ConfigMode.HEX)
        if not isinstance(self.config, HexConfig):
            raise ValueError("This script is designed for HexConfig only")

        PixelStrip, self.is_real = get_library(False)  # Always try real hardware first
        self.pin, self.channel = self.config.pins

        self.strip = PixelStrip(
            num=self.config.get_led_count(),
            pin=self.pin,
            brightness=100,  # Start with lower brightness
            freq_hz=800000,
            dma=10,
            channel=self.channel,
        )
        self.strip.begin()

        # Colors for identifying LEDs in each hexagon
        self.colors = [
            RGBW(255, 0, 0, 0),  # Red
            RGBW(0, 255, 0, 0),  # Green
            RGBW(0, 0, 255, 0),  # Blue
            RGBW(255, 255, 0, 0),  # Yellow
            RGBW(255, 0, 255, 0),  # Magenta
            RGBW(0, 255, 255, 0),  # Cyan
            RGBW(255, 128, 0, 0),  # Orange
            RGBW(128, 0, 255, 0),  # Purple
        ]

        self.color_codes = [
            "\033[91m",  # Red
            "\033[92m",  # Green
            "\033[94m",  # Blue
            "\033[93m",  # Yellow
            "\033[95m",  # Magenta
            "\033[96m",  # Cyan
            "\033[33m",  # Orange
            "\033[35m",  # Purple
        ]

        self.new_hexagons = []

    def clear_all(self):
        """Turn off all LEDs"""
        for i in range(self.config.get_led_count()):
            self.strip.setPixelColor(i, RGBW(0, 0, 0, 0))
        self.strip.show()

    def identify_led_by_subdivision(self, leds: List[int]) -> int:
        """Use binary subdivision to identify a specific LED"""
        if len(leds) == 1:
            # Light up the single LED
            self.clear_all()
            self.strip.setPixelColor(leds[0], RGBW(255, 255, 255, 0))
            self.strip.show()
            print(f"LED {leds[0]} should be lit (white)")
            return 0

        # Split LEDs into groups and light them up
        self.clear_all()

        # Calculate group size (aim for roughly equal groups)
        total_leds = len(leds)
        print(f"Total LEDs: {total_leds}", leds)
        if total_leds <= 8:
            # Small enough - use individual colors
            for i, led_id in enumerate(leds):
                color = self.colors[i % len(self.colors)]
                self.strip.setPixelColor(led_id, color)
                color_name = [
                    "Red",
                    "Green",
                    "Blue",
                    "Yellow",
                    "Magenta",
                    "Cyan",
                    "Orange",
                    "Purple",
                ][i % 8]
                print(
                    f"  Position {i}: {self.color_codes[i % len(self.color_codes)]}{color_name}\033[0m"
                )
            self.strip.show()

            group_input = input(
                f"Which color (1-{total_leds}) contains the bottom LED? "
            ).strip()
            if not group_input.isdigit():
                print("Please enter a color number")
                return self.identify_led_by_subdivision(leds)
            color_num = int(group_input)
            return leds[color_num - 1]
        else:
            # Use groups
            group_size = max(1, total_leds // len(self.colors))
            if total_leds % len(self.colors) != 0:
                group_size += 1

            print(f"Showing {total_leds} LEDs in groups of ~{group_size}:")

            groups = []
            for i in range(0, total_leds, group_size):
                group = leds[i : i + group_size]
                groups.append(group)
                color = self.colors[len(groups) - 1]
                color_name = [
                    "Red",
                    "Green",
                    "Blue",
                    "Yellow",
                    "Magenta",
                    "Cyan",
                    "Orange",
                    "Purple",
                ][len(groups) - 1]

                print(
                    f"  Group {len(groups)}: Positions {i}-{min(i + group_size - 1, total_leds - 1)} = {self.color_codes[len(groups) - 1]}{color_name}\033[0m"
                )

                for led_id in group:
                    self.strip.setPixelColor(led_id, color)

            self.strip.show()

            group_input = input(
                f"Which group (1-{len(groups)}) contains the bottom LED? "
            ).strip()
            if group_input.isdigit():
                group_num = int(group_input)
                if 1 <= group_num <= len(groups):
                    selected_group = groups[group_num - 1]

                    # Recursively subdivide the selected group
                    return self.identify_led_by_subdivision(selected_group)
                else:
                    print(f"Invalid group number. Must be 1-{len(groups)}")
            else:
                print("Please enter a group number")

    def show_hexagon_leds(self, hex_index: int) -> int:
        """Identify which LED is at the bottom using subdivision"""
        hexagon = self.config.hexagons[hex_index]
        leds = hexagon.ordered_leds

        print(f"\nHexagon {hex_index} at position ({hexagon.x}, {hexagon.y})")
        print(f"Has {len(leds)} LEDs")
        print("We'll identify the bottom LED using groups...")

        bottom_pos_led = self.identify_led_by_subdivision(leds)
        bottom_pos = leds.index(bottom_pos_led)

        if bottom_pos is None:
            # Small group - let user pick directly
            while True:
                try:
                    pos_input = input(
                        f"Which position (0-{len(leds)-1}) is the bottom LED? "
                    ).strip()
                    if pos_input.isdigit():
                        pos = int(pos_input)
                        if 0 <= pos < len(leds):
                            return pos
                        else:
                            print(f"Invalid position. Must be 0-{len(leds)-1}")
                    else:
                        print("Please enter a position number")
                except KeyboardInterrupt:
                    raise

        return bottom_pos

    def configure_hexagon(self, hex_index: int) -> List[int]:
        """Configure LED ordering for a single hexagon"""
        hexagon = self.config.hexagons[hex_index]
        leds = hexagon.ordered_leds.copy()

        while True:
            print(f"\nConfiguring hexagon {hex_index} at ({hexagon.x}, {hexagon.y})")
            print("Options:")
            print("  'identify' - Identify the bottom LED using subdivision")
            print("  'test' - Test current ordering with rainbow")
            print("  'ok' - Accept current ordering")
            print("  'skip' - Keep original ordering")

            try:
                user_input = input("Choose action: ").strip().lower()
                print(f"User input: {user_input}")

                if user_input in ["ok", "o"]:
                    print("LED order confirmed!")
                    return leds
                elif user_input in ["skip", "s"]:
                    print("Keeping original LED order")
                    return hexagon.ordered_leds
                elif user_input in ["test", "t"]:
                    self.test_rainbow_hexagon(leds)
                    input("Press Enter to continue configuration...")
                    continue
                elif user_input in ["identify", "i"]:
                    bottom_pos = self.show_hexagon_leds(hex_index)
                    if 0 <= bottom_pos < len(leds):
                        # Shift the array so the bottom LED is first
                        leds = leds[bottom_pos:] + leds[:bottom_pos]
                        print(
                            f"\nShifted array to put LED at position {bottom_pos} first"
                        )
                        print("New ordering: bottom LED is now at position 0")

                        # Show test
                        print(
                            "Showing test rainbow with new ordering, should following ordering starting from bottom and going counter-clockwise:"
                        )
                        print(f"  {self.color_codes[0]}Red\033[0m")
                        print(f"  {self.color_codes[6]}Orange\033[0m")
                        print(f"  {self.color_codes[3]}Yellow\033[0m")
                        print(f"  {self.color_codes[1]}Green\033[0m")
                        print(f"  {self.color_codes[2]}Blue\033[0m")
                        print(f"  {self.color_codes[5]}Cyan\033[0m")
                        print(f"  {self.color_codes[4]}Magenta\033[0m")
                        print(f"  {self.color_codes[7]}Purple\033[0m")
                        self.test_rainbow_hexagon(leds)
                        input("Press Enter to continue (or choose 'ok' to confirm)...")
                    else:
                        print(f"Invalid position: {bottom_pos}")
                else:
                    print("Invalid input. Choose 'identify', 'test', 'ok', or 'skip'")

            except KeyboardInterrupt:
                print("\nConfiguration cancelled")
                raise
            except Exception as e:
                print(f"Error: {e}")

    def test_rainbow_hexagon(self, leds: List[int]):
        """Show rainbow pattern on a single hexagon to verify ordering"""
        self.clear_all()

        # Create rainbow colors
        num_leds = len(leds)
        for i, led_id in enumerate(leds):
            # HSV rainbow: vary hue from 0 to 360
            hue = (i * 360) // num_leds
            r, g, b = self.hsv_to_rgb(hue, 1.0, 1.0)
            self.strip.setPixelColor(led_id, RGBW(int(r), int(g), int(b), 0))

        self.strip.show()

    def hsv_to_rgb(self, h: float, s: float, v: float) -> Tuple[float, float, float]:
        """Convert HSV to RGB"""
        import math

        h = h / 60.0
        i = int(h)
        f = h - i
        p = v * (1 - s)
        q = v * (1 - s * f)
        t = v * (1 - s * (1 - f))

        if i == 0:
            return (v * 255, t * 255, p * 255)
        elif i == 1:
            return (q * 255, v * 255, p * 255)
        elif i == 2:
            return (p * 255, v * 255, t * 255)
        elif i == 3:
            return (p * 255, q * 255, v * 255)
        elif i == 4:
            return (t * 255, p * 255, v * 255)
        else:
            return (v * 255, p * 255, q * 255)

    def test_all_rainbow(self):
        """Test mode: show static rainbow on all hexagons"""
        self.clear_all()

        print("Test mode: All hexagons showing rainbow patterns")
        print("Each hexagon should show a smooth rainbow counter-clockwise from bottom")

        for hex_index, hexagon in enumerate(self.new_hexagons):
            leds = hexagon.ordered_leds
            num_leds = len(leds)

            for i, led_id in enumerate(leds):
                hue = (i * 360) // num_leds
                r, g, b = self.hsv_to_rgb(hue, 1.0, 0.8)  # Slightly dimmer
                self.strip.setPixelColor(led_id, RGBW(int(r), int(g), int(b), 0))

        self.strip.show()

    def run_configuration(self):
        """Run the full configuration process"""
        print("LED Order Configuration Tool")
        print("=" * 40)
        print()
        print("This tool helps you configure LED ordering so that:")
        print("- The first LED in each hexagon is at the bottom")
        print("- LEDs are ordered counter-clockwise from the bottom")
        print()

        if not self.is_real:
            print(
                "WARNING: Using mock LED implementation. Connect to real hardware for actual configuration."
            )
            print()

        try:
            for hex_index, hexagon in enumerate(self.config.hexagons):
                print(f"\n{'='*50}")
                print(
                    f"Configuring Hexagon {hex_index + 1}/{len(self.config.hexagons)}"
                )
                print(f"Position: ({hexagon.x}, {hexagon.y})")

                new_leds = self.configure_hexagon(hex_index)

                # Create new hexagon with updated LED order
                from config import Hexagon

                new_hex = Hexagon(hexagon.x, hexagon.y, new_leds)
                self.new_hexagons.append(new_hex)

            # Final test
            print(f"\n{'='*50}")
            print("Configuration complete! Running final test...")
            self.test_all_rainbow()

            input("\nPress Enter to see the new configuration code...")

            # Generate new configuration
            self.print_new_configuration()

        except KeyboardInterrupt:
            print("\n\nConfiguration cancelled by user")
            self.print_new_configuration()
        finally:
            self.clear_all()

    def print_new_configuration(self):
        """Print the new configuration code"""
        print(f"\n{'='*60}")
        print("NEW CONFIGURATION")
        print(f"{'='*60}")
        print()
        print("Replace the hexagons list in your HexConfig class with:")
        print()
        print("self.hexagons = [")

        for hexagon in self.new_hexagons:
            led_str = ", ".join(map(str, hexagon.ordered_leds))
            print(f"    Hexagon({hexagon.x}, {hexagon.y}, [{led_str}]),")

        print("]")
        print()
        print(
            "Copy this code into your config.py file in the HexConfig.__init__() method"
        )


def main():
    """Main entry point"""
    try:
        configurator = LEDOrderConfigurator()
        configurator.run_configuration()
    except KeyboardInterrupt:
        print("\n\nConfiguration cancelled by user")
        sys.exit(0)
    except Exception as e:
        print(f"Error: {e}")
        sys.exit(1)


if __name__ == "__main__":
    main()

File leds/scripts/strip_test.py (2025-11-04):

import sys
import time
import argparse
from pathlib import Path
from typing import List, Tuple

# Add parent directories to path
sys.path.append(str(Path(__file__).parent.parent.parent))

from leds.color import RGBW
from leds.controllers.controller_base import get_library
from leds.mock import MockPixelStrip


def main():
    parser = argparse.ArgumentParser(
        description="LED performance test for multiple strips"
    )
    parser.add_argument(
        "--config",
        action="append",
        help="Strip configuration as 'pin,channel,pin_count' (can be specified multiple times)",
    )
    args = parser.parse_args()

    if not args.config:
        print("Error: At least one --config must be specified")
        print("Example: --config '18,0,300' --config '19,1,150'")
        sys.exit(1)

    # Parse configurations
    strips: List[Tuple[MockPixelStrip, int]] = []
    PixelStrip, _ = get_library(False)

    for config_str in args.config:
        try:
            pin, channel, pin_count = map(int, config_str.split(","))
            strip = PixelStrip(
                num=pin_count,
                pin=pin,
                brightness=25,
                freq_hz=800000,
                dma=10,
                channel=channel,
            )
            strip.begin()
            strips.append((strip, pin_count))
            print(f"Initialized strip: pin={pin}, channel={channel}, LEDs={pin_count}")
        except ValueError as e:
            print(f"Error parsing config '{config_str}': {e}")
            sys.exit(1)

    def wheel(pos: int) -> RGBW:
        """Generate rainbow colors across 0-255 positions."""
        if pos < 85:
            return RGBW(pos * 3, 255 - pos * 3, 0, 0)
        elif pos < 170:
            pos -= 85
            return RGBW(255 - pos * 3, 0, pos * 3, 0)
        else:
            pos -= 170
            return RGBW(0, pos * 3, 255 - pos * 3, 0)

    def rainbow_cycle(wait: float) -> None:
        """Draw rainbow that uniformly distributes itself across all strips."""
        frame_count = 0
        start_time = time.time()

        while True:
            for j in range(256):
                # Update all strips in parallel
                for strip, pin_count in strips:
                    for i in range(pin_count):
                        pixel_index = (i * 256 // pin_count) + j
                        strip.setPixelColor(i, wheel(pixel_index & 255))

                # Show all strips
                for strip, _ in strips:
                    strip.show()

                time.sleep(wait)
                frame_count += 1

                # Log FPS every second
                current_time = time.time()
                if current_time - start_time >= 1.0:
                    print(f"FPS: {frame_count}")
                    frame_count = 0
                    start_time = current_time

    try:
        rainbow_cycle(0.001)
    except KeyboardInterrupt:
        # Turn off all LEDs on exit
        for strip, pin_count in strips:
            for i in range(pin_count):
                strip.setPixelColor(i, RGBW(0, 0, 0, 0))
            strip.show()


if __name__ == "__main__":
    main()

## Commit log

2025-04-12 Remove stdl
    [led-scales-printable.stl]
2025-04-12 Remove unused scad file
    [led-scales.scad]
2025-04-12 Move all to cad/
2025-04-12 add led visualizer (wip)
2025-04-13 Wrap leds in a controller
2025-05-02 Pick current effect in web UI
2025-05-04 Add power button
2025-08-18 use print_outside_padding
2025-08-27 Ensure no empty printed tiles
2025-09-21 Use hex buttons to pick hexes during setup
2025-09-21 Revert "Use hex buttons to pick hexes during setup"
    This reverts commit 12601e04180d53b0fb402a56a76ff49637f29ecb.
2025-09-22 Re-use previous led index when pressing enter in setup mode
2025-09-22 Update text printed when booting
2025-10-15 Enhance configuration management and WebSocket updates in LEDs class. Save full configuration data, emit state, effects, and presets updates on relevant actions, and ensure full state is emitted on c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
2025-10-22 Add pin and channel args options to performance test
2025-11-03 Change scale pin
2026-05-14 Add power_on_at_startup feature to API and UI
2026-05-14 Refactor startup power handling in API and UI; integrate power_on_at_startup into /state endpoint
2026-05-14 Add LED scales demo assets (MP4, CAD PNG, GIF)
2026-05-14 README: add Preview section with demo GIF and CAD image
2026-05-16 Enhance WebSocket handling in LEDs class: add client connection tracking and safe emit method to prevent race conditions. Update setup.py to require python-engineio version 4.8.0 for improved stabili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
2026-05-27 Add device ID generation to LEDs class and include it in state responses
2026-05-27 Set device ID before startup
